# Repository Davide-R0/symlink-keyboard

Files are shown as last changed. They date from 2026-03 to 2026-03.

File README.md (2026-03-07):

# Keyboard

## Tools

- Build123d: for the viewer look [external editors](https://build123d.readthedocs.io/en/latest/external.html#external), in general we use: `yet-another-cad-viewer` (c'è una estensione per nvim o vscode?)
- SKiDL: to convert form kicad use tool: `netlist_to_skidl` (TODO: setup kicad liberary for this)
- Openscad to build123 migration: [look here](https://build123d.readthedocs.io/en/latest/OpenSCAD.html)
- for the pcb routing still use kicad editor

## General proprieties

- Layout `4x6+5`
- Parte sinistra il master, destro slave
- Si pososno caricare due firmwere diversi:
  - Bluetooth tra le due parti, se collegato il cavo intermedio e collegato il master al pc si caricano entrambe le schede. In entrambi i casi si può o collegare col cavo al pc per avere cablato il master o col bluetooth col master.
  - Cablato tra le due parti, in questo caso bisogna collegare il cavo tra le due parti e poi si può decidere se collegarla al pc tramite bluetooth o cavo con il master.
- led rgb per key e anche sul retro (led sotto tasti e sul retro sono in due lineee dati separati perchè quando va con batteria funzionano solo quelli sul retro, quando colelgato via cavo funzionano entrambi)
- schermo oled e potenziometro per lato
- Case "Sandwich Mount"
- Framework: `ZMK`, si possono creare moduli in C, supporta BLE e il nice!nano v2.
- Round trackpad (Circle Touchpad), mini touchpad. Il `TM023023-2024` su `Mouser` (c'è sia con overlay che senza, si può usare un nastro personalizzato se si vuole: ) per il connettore: connettore FPC 12-pin, 0.5mm pitch, bottom contact (52746-1271 ?). Altrimenti già completo (ma grande): [splitkb](https://splitkb.com/products/halcyon-cirque-touchpad-module?_pos=1&_sid=2299becd1&_ss=r). NOTA: forse ci sta anche al verisone da 35mm di diametro)

## Components

- Un micorcontroller `nice!nano v2` per lato (Pro Micro NRF52840) (Amazon o Aliexpress)
- Una batteria per lato sotto il microcontroller: `303040`, per la batteria forse fare un dopio fondo (cioè tagliare la back pcb e metterne un'altra che sporge di più sul retro così da poter mettere batterie più spesse (503040 o 503050)) (Aliexpress)
NOTE: le batterie anderebbero sempre circa 400-500mA (`403040`) a destra e 700-800mA (`403050`) a sinistra per consumo giusto.
- Un pannello oled per lato `0.91 inch OLED LCD Display IIC 128×32` (Amazon o Aliexpress)
- Un potenziometro a sinistra: `EC11` con click (LCSC)
- Un Circle Touchpad a destra: [splitkb](https://splitkb.com/products/halcyon-cirque-touchpad-module?_pos=1&_sid=2299becd1&_ss=r). Per la connesisone c'è bisogno di:
  - FPC a 12 pin: `FPC-05F-6PH20` (LCSC) (NOTE: è difficile da saldare? se dovesse essere cercare i "FPC to DIP breakout 12 pin 0.5mm")
  - Per il trackpad c'è un problema: macano i pin, bisogna usare un io expander: `PCA9536D` (4 pin extra) (LCSC)
- I switch `Kailh Choc V2 'Deep Sea' Brown` (tattili, low profile, silenziosi, con alloggio a croce) (Aliexpress)
- Socket per i switch `Kailh Choc Low Profile Socket` compatibili con choc. (Aliexpress) TODO: rivedere socket compatibili!
- Led rgb `SK6812MINI-E` per switch (trought hole) (LCSC)
- Led RGB `SK6812-5050` per la retorilluminazione (x6 per lato) (LCSC)a
- Per i led rgb di va un circuito che scollega l'alimentazione se non servonoe:
  - -- Transistor P-CH mosfet: `AO3401A` SOT-23 (LCSC)
  - -- Transistor N-CH mosfet: `AO3400A` SOT-23 (LCSC)
  - -- Resistena 100kohm: `ERJ6ENF1003V` 0805, per il pull-down per il P-CH (LCSC)
  - -- Resistena 10kohm: `TE05H1002BT` 0805, per il pull-up per il N-CH (LCSC)
  - Al posto dei mosfet grandi e resistenze meglio come: `TPS22917` + condensatore da 1nF: `CL21C102JBCNNNC` (LCSC)
- Resistenze 4.7kohm: `ERJU6RD4701V` 0805, per pullup per SDA e SCL (LCSC)
- Resistenza 400ohm: `TR0805B400RP0525Z` 0805, per l'ingresso DIN dei led (potrebbero esserci sovralimentazioni) (LCSC)
- Diodi: `1N4148W-E3-08` in SOD-123 per i led (cambiare il formato per facilità di saldatura?) (LCSC)
- Connection between split:
  - usb-c ports x2: `TYPE-C 16PIN 2MD`, per connessione tra due parti (LCSC)
  - ESD protection (Chip TVS): `USBLC6-2SC6`
  - PTC fuse (6V 1.5-2A): `1206L150/6V` (NOTE: forse meglio da 2A `1206L200/6V`) (LCSC)
  - Filtro RC per lo shield del usb-c: resistenza: (1kOhm) `RC0805FR-071KL`, condensatore (100nF 100V X7R) `CC0805X7R100V104MN`
  - Resistenza (5.1kohm): `0805W8F5101T5E`, per le connessioni pull-down CC1 CC2 (per alimentaizone)
  - Resistenza (22kohm) con supporto da 1.5A: `ERJ6ENF2202V`, per le connessioni pull-up CC1 CC2 (per alimentaizone)
  - Ideal Diode IC: `MAX40200AUK+T`, per il ritorno di corrente dalla porta (LCSC)
  - --Load switch IO (per protezione da correnti inverse): `TPS22918`
  - -- Diodi Zener da 3.3V: `BZT52C3V3-E3-18`, per protezione da collegamento scorretto (SOD-123) (LCSC)
  - -- resistenze: `0805W8F1000T5E`, 100 ohm 0805 per protezione da collegamento scorretto (LCSC)
- headers low profile: `Mill-Max Mfg. Corp. 315-43-112-41-003000`, to connect the nice!nano to the main pcb (and also the oled display) (LCSC) (OLD: header female connectors: `PM2.54-1X8PM-H85` (o altre versioni...))
- brass spacers M2 (+ viti): `Kit distanziatore in ottone` (Aliexpress)
- slider switch SMD : `PCM12SMTR`, per accendere/spegnere la batteria per ogni lato (LCSC)
- button SMD: verticale: `TL3342F450QG` oppure laterale: `SKSCLDE010`, per mettere la scheda in modalità bootloader. (LCSC)
- PCBs: "Sandwich Mount":
  - Layout:
    - Top Plate: dove voengono incastrati i switch
    - Main PCB: dove c'è tuta la elettornica
    - Bottom Plate: per proteggere la eletronica deall'esterno.
  - Il tutto connesso isnieme con viti M.2 e distanziali in ottone:
    - Tra il main pcb e il Top plate non is mettono distanziali perchè sono gli switch a tenere il palte.
    - Tra main pcb e botton plate: distanziali tra `6-8mm`.
  - Per la pendenza o si mettono distanziali assimmetrici,oppure si usa il `Tenting Puck`, (JLCPCB)
- Livellatore di tensione (Level Shifter): `SN74LVC1T45DBVR` per la linea dati dei led (LCSC)
- Per prioteggere sovratensioni TX/RX un Logic Buffer: `SN74LVC2G34DBVR` (LCSC)
- --Diodo Schottky: `SS14`, per il ritorno della batteria quando sono collegati tramite filo le due parti (LCSC)
- Kampton tape: per l'isolamento e resistenza al calore (Aliexpress)
- Pasta saldante: per componenti smd (Aliexpress)

Switch Kailh Choc V2: Ottimi, ma ricorda che hanno un'altezza diversa dai V1. Il tuo "Top Plate" deve avere uno spessore di $1.2\text{ mm}$ o $1.5\text{ mm}$ (taglio laser o PCB) per permettere agli switch di "cliccare" correttamente in posizione.

NOTE: per i componenti smd i formati da scegliere sono:

- SOT-23 per i chip a più gambe
- 0805 per R, C e componenti a 2 gambe

QT_QPA_PLATFORM=xcb freecad

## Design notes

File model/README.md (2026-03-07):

per i distanziatori esagonali e per lassemblaggio delel parti (dove si possono definire gli "anchors") usare la libreria: `BOSL2`

Ad esempio: 
include <BOSL2/std.scad>

// Il cubo non è al centro, ma "poggia" sul piano con la faccia inferiore
cuboid([20, 20, 20], anchor=BOTTOM);

cuboid([10, 10, 5], anchor=BOTTOM) {
    attach(TOP) 
        cyl(d=3, l=10, anchor=BOTTOM);
}

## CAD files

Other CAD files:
model/legacy/config.scad
model/legacy/main.scad
model/legacy/main-plate/main-plate.scad

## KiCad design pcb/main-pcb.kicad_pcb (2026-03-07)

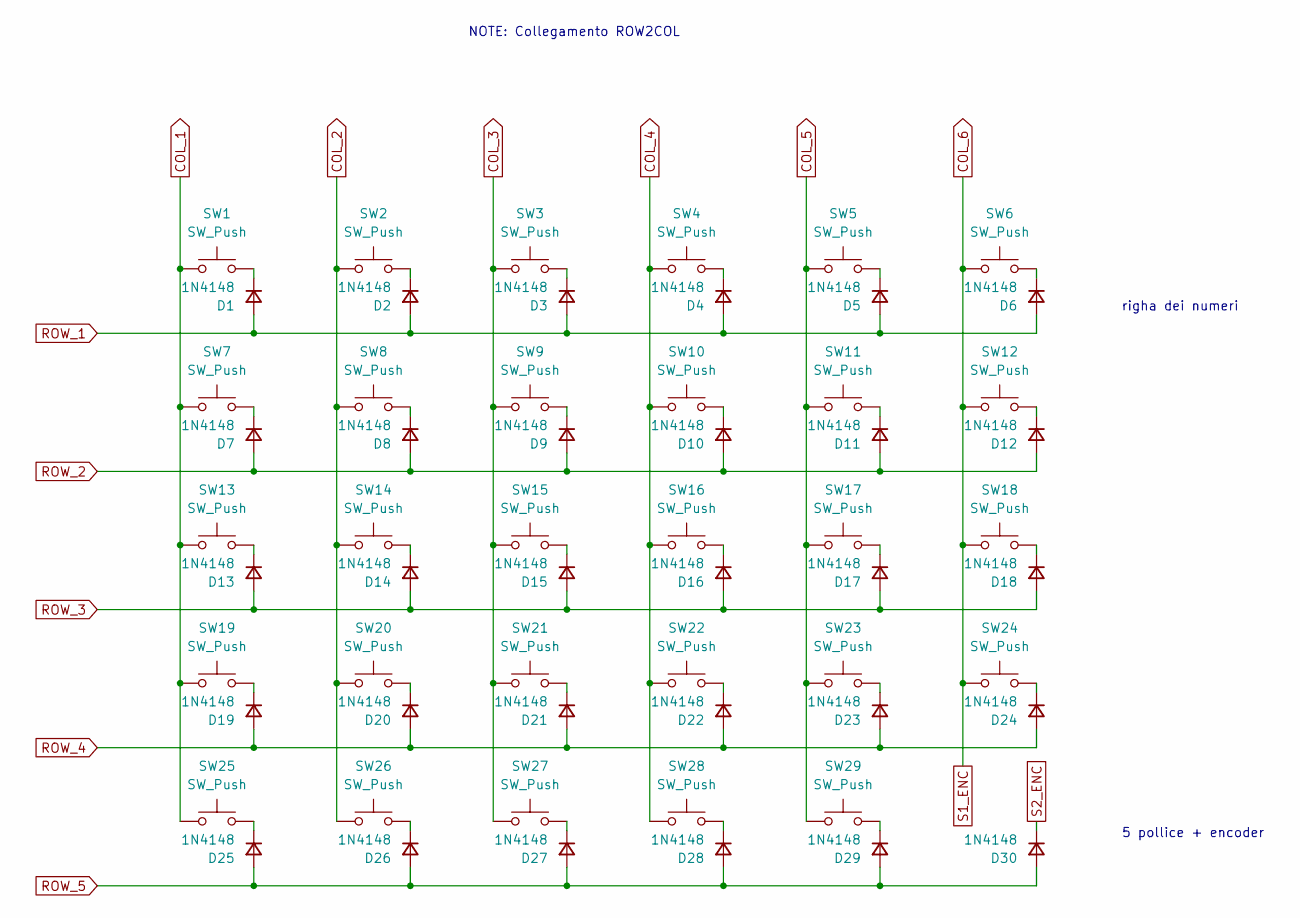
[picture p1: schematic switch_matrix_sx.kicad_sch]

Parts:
D1, D2, D3, D4, D5, D6, D7, D8, D9, D10, D11, D12, D13, D14, D15, D16, D17, D18, D19, D20, D21, D22, D23, D24, D25, D26, D27, D28, D29, D30: 1N4148; D_SOD-123
SW1, SW2, SW3, SW4, SW5, SW6, SW7, SW8, SW9, SW10, SW11, SW12, SW13, SW14, SW15, SW16, SW17, SW18, SW19, SW20, SW21, SW22, SW23, SW24, SW25, SW26, SW27, SW28, SW29: SW_Push; SW_Hotswap_Kailh_Choc_V2_1.00u

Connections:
COL_1: SW1.1, SW7.1, SW13.1, SW19.1, SW25.1; also elsewhere on the board
COL_2: SW2.1, SW8.1, SW14.1, SW20.1, SW26.1; also elsewhere on the board
COL_3: SW3.1, SW9.1, SW15.1, SW21.1, SW27.1; also elsewhere on the board
COL_4: SW4.1, SW10.1, SW16.1, SW22.1, SW28.1; also elsewhere on the board
COL_5: SW5.1, SW11.1, SW17.1, SW23.1, SW29.1; also elsewhere on the board
COL_6: SW6.1, SW12.1, SW18.1, SW24.1; also elsewhere on the board
unnamed: D1.1 (K), SW1.2
unnamed: D2.1 (K), SW2.2
unnamed: D3.1 (K), SW3.2
unnamed: D4.1 (K), SW4.2
unnamed: D5.1 (K), SW5.2
unnamed: D6.1 (K), SW6.2
unnamed: D7.1 (K), SW7.2
unnamed: D8.1 (K), SW8.2
unnamed: D9.1 (K), SW9.2
unnamed: D10.1 (K), SW10.2
unnamed: D11.1 (K), SW11.2
unnamed: D12.1 (K), SW12.2
unnamed: D13.1 (K), SW13.2
unnamed: D14.1 (K), SW14.2
unnamed: D15.1 (K), SW15.2
unnamed: D16.1 (K), SW16.2
unnamed: D17.1 (K), SW17.2
unnamed: D18.1 (K), SW18.2
unnamed: D19.1 (K), SW19.2
unnamed: D20.1 (K), SW20.2
unnamed: D21.1 (K), SW21.2
unnamed: D22.1 (K), SW22.2
unnamed: D23.1 (K), SW23.2
unnamed: D24.1 (K), SW24.2
unnamed: D25.1 (K), SW25.2
unnamed: D26.1 (K), SW26.2
unnamed: D27.1 (K), SW27.2
unnamed: D28.1 (K), SW28.2
unnamed: D29.1 (K), SW29.2
ROW_1: D1.2 (A), D2.2 (A), D3.2 (A), D4.2 (A), D5.2 (A), D6.2 (A); also elsewhere on the board
ROW_2: D7.2 (A), D8.2 (A), D9.2 (A), D10.2 (A), D11.2 (A), D12.2 (A); also elsewhere on the board
ROW_3: D13.2 (A), D14.2 (A), D15.2 (A), D16.2 (A), D17.2 (A), D18.2 (A); also elsewhere on the board
ROW_4: D19.2 (A), D20.2 (A), D21.2 (A), D22.2 (A), D23.2 (A), D24.2 (A); also elsewhere on the board
ROW_5: D25.2 (A), D26.2 (A), D27.2 (A), D28.2 (A), D29.2 (A), D30.2 (A); also elsewhere on the board
S2_ENC: D30.1 (K); also elsewhere on the board

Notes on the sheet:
NOTE: Collegamento ROW2COL
5 pollice + encoder
righa dei numeri

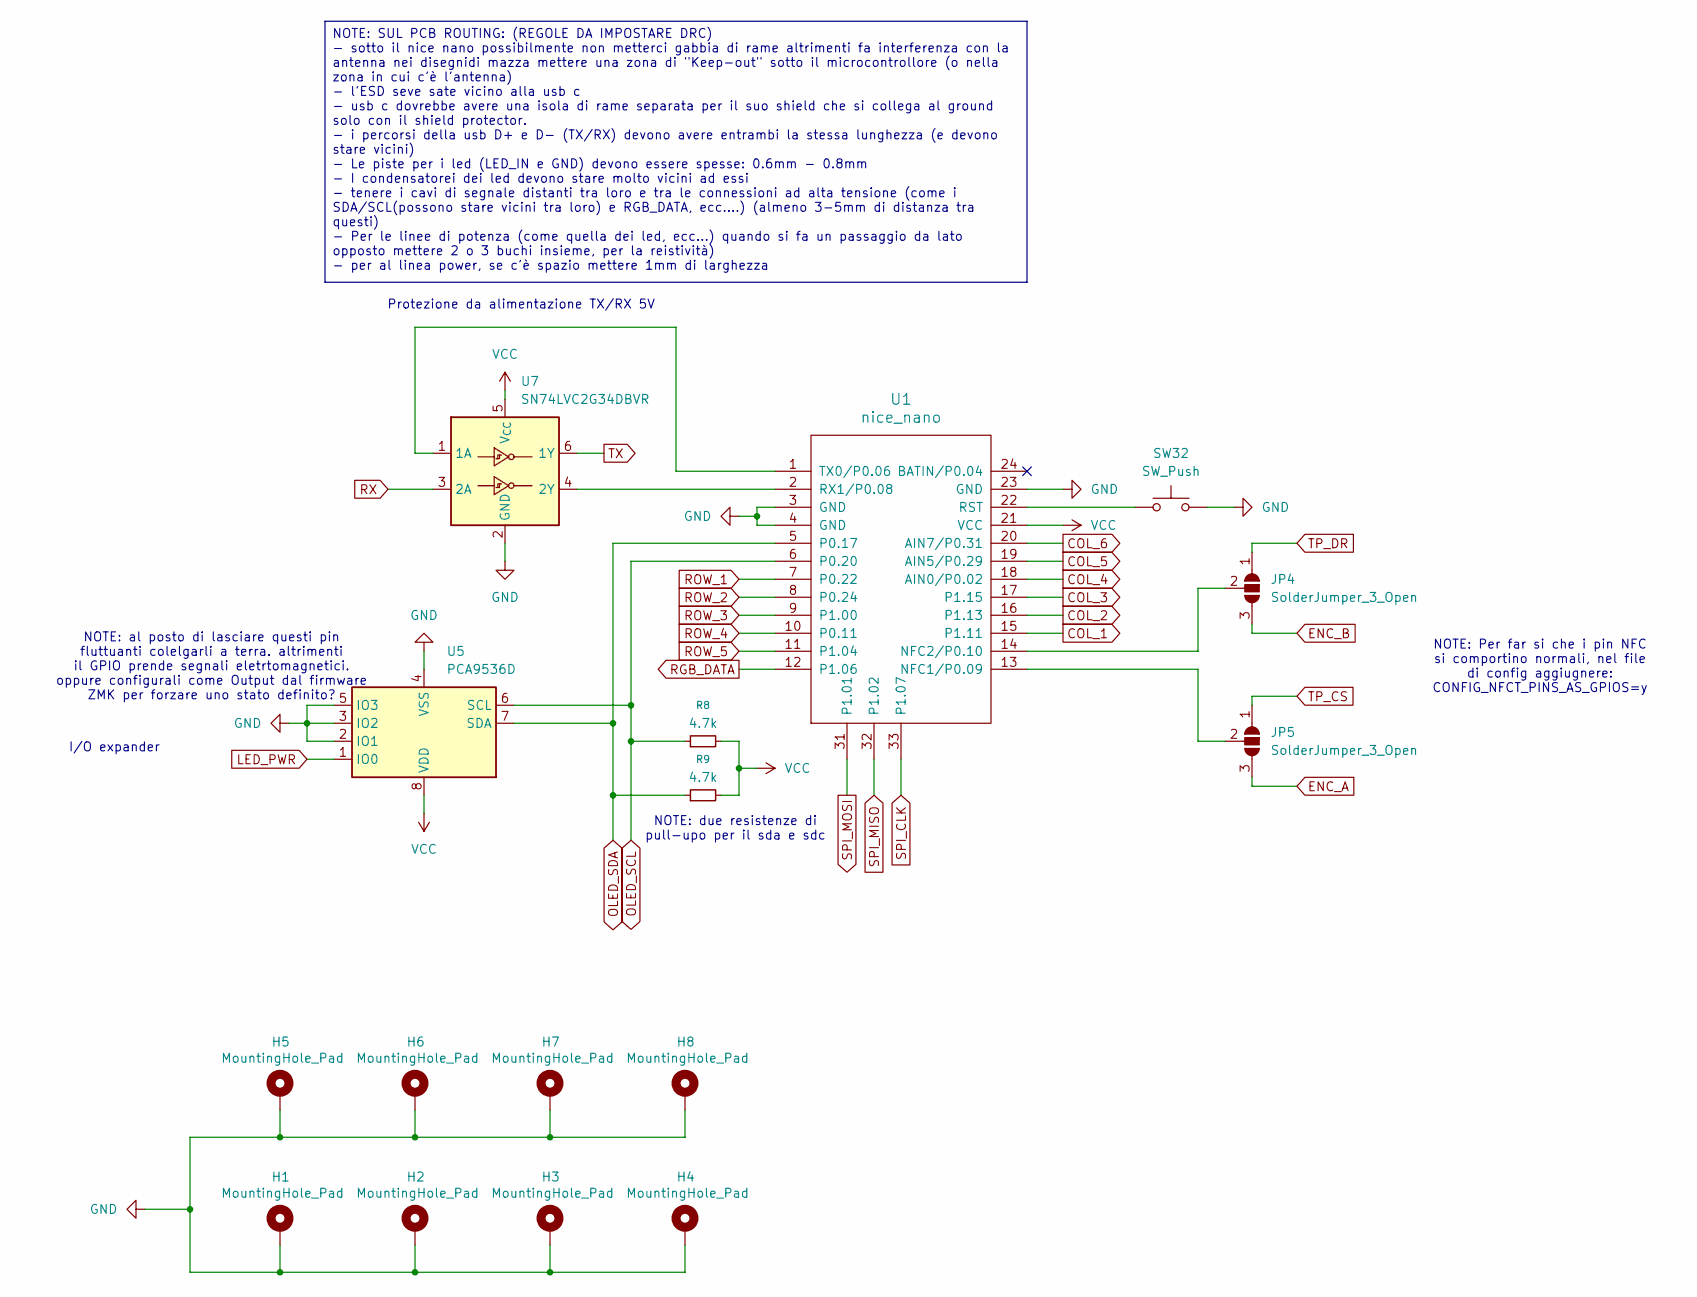
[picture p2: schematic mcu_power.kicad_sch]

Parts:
H1, H2, H3, H4, H5, H6, H7, H8: MountingHole_Pad
JP4, JP5: SolderJumper_3_Open; SolderJumper-3_P1.3mm_Open_RoundedPad1.0x1.5mm_NumberLabels
R8, R9: 4.7k; R_0805_2012Metric_Pad1.20x1.40mm_HandSolder
SW32: SW_Push; SW_SPST_TL3342
U1: nice_nano
U5: PCA9536D; SOIC-8_3.9x4.9mm_P1.27mm
U7: SN74LVC2G34DBVR; SOT-23-6

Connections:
COL_1: U1.15 (P1.11); also elsewhere on the board
COL_2: U1.16 (P1.13); also elsewhere on the board
COL_3: U1.17 (P1.15); also elsewhere on the board
COL_4: U1.18 (AIN0/P0.02); also elsewhere on the board
COL_5: U1.19 (AIN5/P0.29); also elsewhere on the board
COL_6: U1.20 (AIN7/P0.31); also elsewhere on the board
ENC_A: JP5.3 (B); also elsewhere on the board
ENC_B: JP4.3 (B); also elsewhere on the board
GND: H1.1, H2.1, H3.1, H4.1, H5.1, H6.1, H7.1, H8.1, SW32.2, U1.3 (GND), U1.4 (GND), U1.23 (GND), U5.2 (IO1), U5.3 (IO2), U5.4 (VSS), U5.5 (IO3), U7.2 (GND); also elsewhere on the board
LED_PWR: U5.1 (IO0); also elsewhere on the board
unnamed: JP4.2 (C), U1.14 (NFC2/P0.10)
unnamed: JP5.2 (C), U1.13 (NFC1/P0.09)
unnamed: SW32.1, U1.22 (RST)
unnamed: U1.2 (RX1/P0.08), U7.4 (2Y)
unnamed: U1.1 (TX0/P0.06), U7.1 (1A)
OLED_SCL: R8.1, U1.6 (P0.20), U5.6 (SCL); also elsewhere on the board
OLED_SDA: R9.1, U1.5 (P0.17), U5.7 (SDA); also elsewhere on the board
RGB_DATA: U1.12 (P1.06); also elsewhere on the board
ROW_1: U1.7 (P0.22); also elsewhere on the board
ROW_2: U1.8 (P0.24); also elsewhere on the board
ROW_3: U1.9 (P1.00); also elsewhere on the board
ROW_4: U1.10 (P0.11); also elsewhere on the board
ROW_5: U1.11 (P1.04); also elsewhere on the board
RX: U7.3 (2A); also elsewhere on the board
SPI_CLK: U1.33 (P1.07); also elsewhere on the board
SPI_MISO: U1.32 (P1.02); also elsewhere on the board
SPI_MOSI: U1.31 (P1.01); also elsewhere on the board
TP_CS: JP5.1 (A); also elsewhere on the board
TP_DR: JP4.1 (A); also elsewhere on the board
TX: U7.6 (1Y); also elsewhere on the board
VCC: R8.2, R9.2, U1.21 (VCC), U5.8 (VDD), U7.5 (V_{CC}); also elsewhere on the board

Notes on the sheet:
NOTE: Per far si che i pin NFC si comportino normali, nel file di config aggiugnere: CONFIG_NFCT_PINS_AS_GPIOS=y
NOTE: al posto di lasciare questi pin fluttuanti colelgarli a terra. altrimenti il GPIO prende segnali eletrtomagnetici. oppure configurali come Output dal firmware ZMK per forzare uno stato definito?
I/O expander
Protezione da alimentazione TX/RX 5V
NOTE: due resistenze di pull-upo per il sda e sdc
NOTE: SUL PCB ROUTING: (REGOLE DA IMPOSTARE DRC) - sotto il nice nano possibilmente non metterci gabbia di rame altrimenti fa interferenza con la antenna nei disegnidi mazza mettere una zona di "Keep-out" sotto il microcontrollore (o nella zona in cui c'è l'antenna) - l'ESD seve sate vicino alla us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

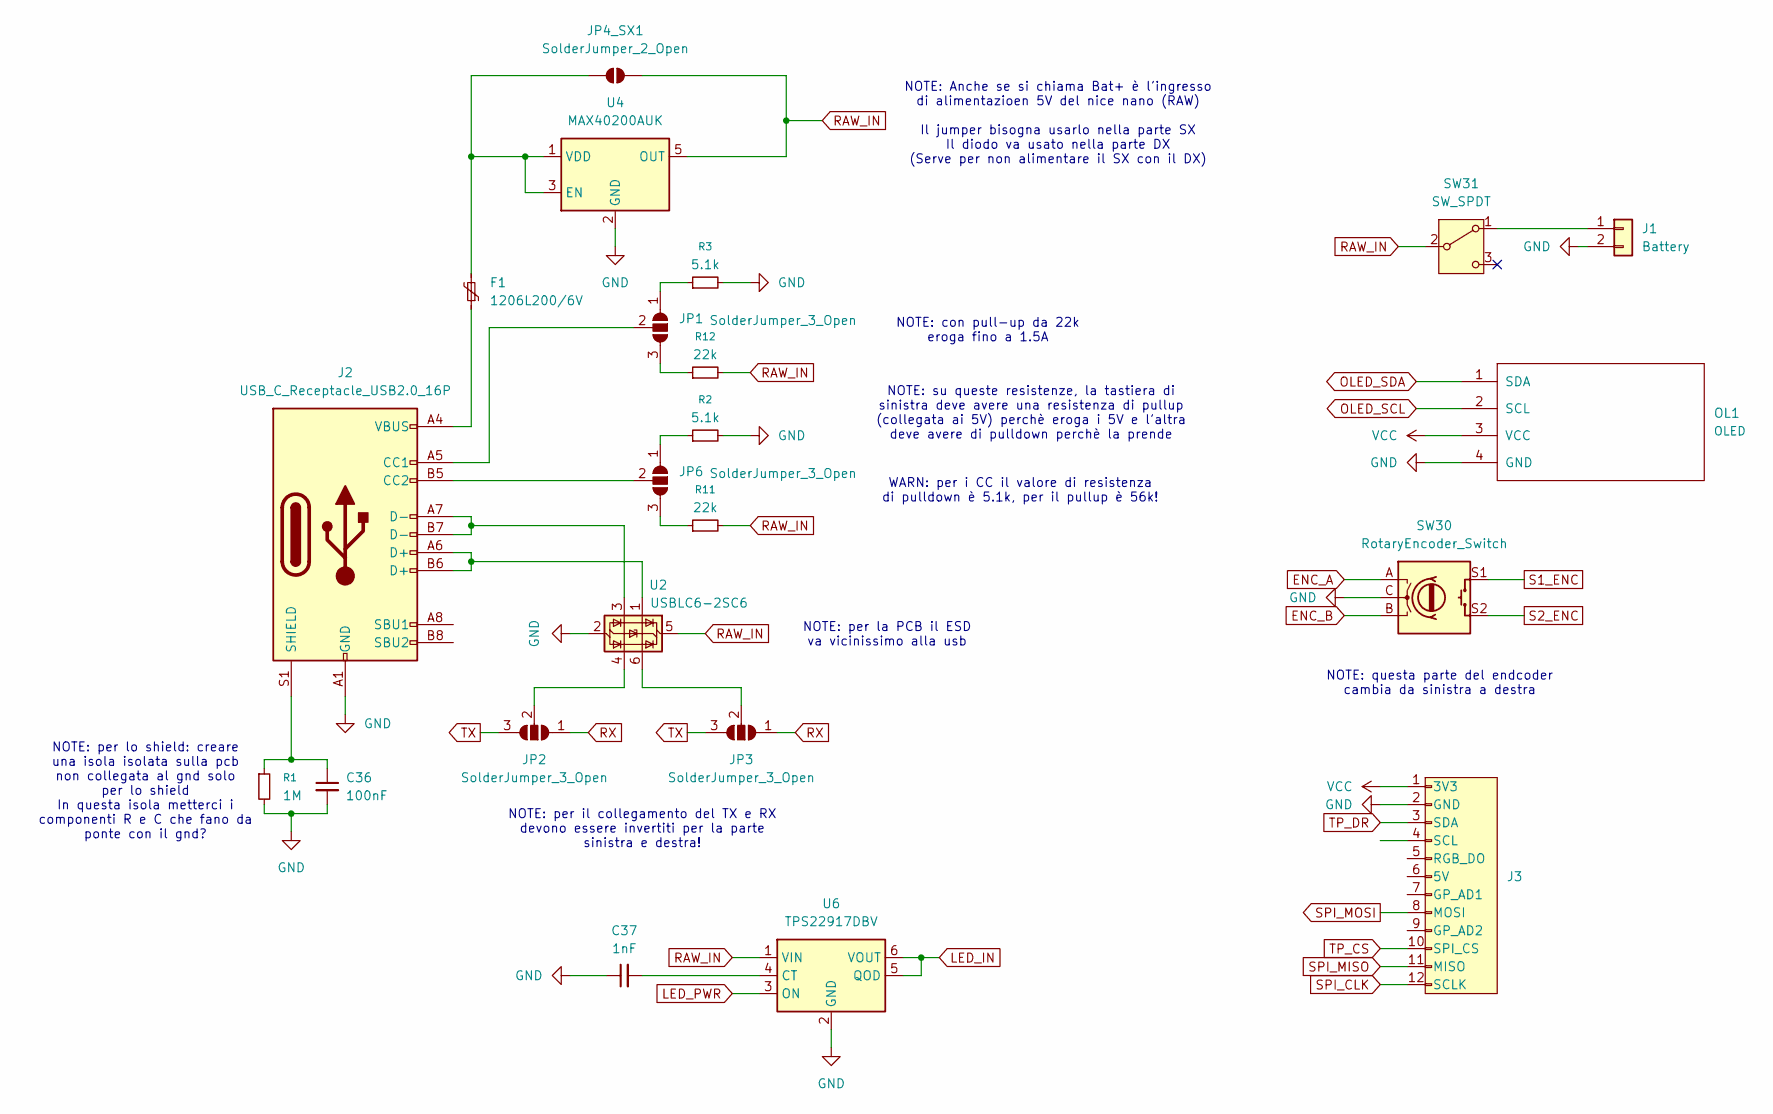
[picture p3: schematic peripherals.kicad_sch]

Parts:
C36: 100nF; C_0805_2012Metric_Pad1.18x1.45mm_HandSolder
C37: 1nF; C_0805_2012Metric_Pad1.18x1.45mm_HandSolder
F1: 1206L200/6V; Fuse_1206_3216Metric
J1: Battery; JST_PH_S2B-PH-K_1x02_P2.00mm_Horizontal
J2: USB_C_Receptacle_USB2.0_16P; USB_C_Receptacle_HRO_TYPE-C-31-M-12
J3: JUSHUO_AFA07-S12FCA-00_1x12-1MP_P1.0mm_Horizontal
JP1, JP2, JP3, JP6: SolderJumper_3_Open; SolderJumper-3_P1.3mm_Open_RoundedPad1.0x1.5mm_NumberLabels
JP4_SX1: SolderJumper_2_Open; SolderJumper-2_P1.3mm_Open_RoundedPad1.0x1.5mm
OL1: OLED; OLED_v2
R1: 1M; R_0805_2012Metric_Pad1.20x1.40mm_HandSolder
R2, R3: 5.1k; R_0805_2012Metric_Pad1.20x1.40mm_HandSolder
R11, R12: 22k; R_0805_2012Metric_Pad1.20x1.40mm_HandSolder
SW30: RotaryEncoder_Switch; RotaryEncoder_Alps_EC11E-Switch_Vertical_H20mm
SW31: SW_SPDT; SW_SPDT_PCM12
U2: USBLC6-2SC6; SOT-23-6
U4: MAX40200AUK; SOT-23-5
U6: TPS22917DBV; SOT-23-6

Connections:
COL_6: SW30.S1; also elsewhere on the board
ENC_A: SW30.A; also elsewhere on the board
ENC_B: SW30.B; also elsewhere on the board
GND: C36.2, C37.1, J1.2, J2.A1 (GND), J2.A12 (GND), J2.B1 (GND), J2.B12 (GND), J3.2 (GND), OL1.4 (GND), R1.2, R2.2, R3.2, SW30.C, U2.2 (GND), U4.2 (GND), U6.2 (GND); also elsewhere on the board
LED_IN: U6.5 (QOD), U6.6 (VOUT); also elsewhere on the board
LED_PWR: U6.3 (ON); also elsewhere on the board
unnamed: F1.1, J2.A4 (VBUS), J2.A9 (VBUS), J2.B4 (VBUS), J2.B9 (VBUS)
unnamed: J1.1, SW31.1 (A)
unnamed: J2.A5 (CC1), JP1.2 (C)
unnamed: J2.B5 (CC2), JP6.2 (C)
unnamed: J2.A6 (D+), J2.B6 (D+), U2.1 (I/O1)
unnamed: J2.A7 (D-), J2.B7 (D-), U2.3 (I/O2)
unnamed: C36.1, J2.S1 (SHIELD), R1.1
unnamed: JP1.1 (A), R3.1
unnamed: JP1.3 (B), R12.1
unnamed: JP2.2 (C), U2.4 (I/O2)
unnamed: JP3.2 (C), U2.6 (I/O1)
unnamed: F1.2, JP4_SX1.2 (B), U4.1 (VDD), U4.3 (EN)
unnamed: JP6.1 (A), R2.1
unnamed: JP6.3 (B), R11.1
unnamed: C37.2, U6.4 (CT)
OLED_SCL: OL1.2 (SCL); also elsewhere on the board
OLED_SDA: OL1.1 (SDA); also elsewhere on the board
RAW_IN: JP4_SX1.1 (A), R11.2, R12.2, SW31.2 (B), U2.5 (VBUS), U4.5 (OUT), U6.1 (VIN); also elsewhere on the board
RX: JP2.1 (A), JP3.1 (A); also elsewhere on the board
S2_ENC: SW30.S2; also elsewhere on the board
SPI_CLK: J3.12 (SCLK); also elsewhere on the board
SPI_MISO: J3.11 (MISO); also elsewhere on the board
SPI_MOSI: J3.8 (MOSI); also elsewhere on the board
TP_CS: J3.10 (SPI_CS); also elsewhere on the board
TP_DR: J3.3 (SDA); also elsewhere on the board
TX: JP2.3 (B), JP3.3 (B); also elsewhere on the board
VCC: J3.1 (3V3), OL1.3 (VCC); also elsewhere on the board

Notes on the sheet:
NOTE: per lo shield: creare una isola isolata sulla pcb non collegata al gnd solo per lo shield In questa isola metterci i componenti R e C che fano da ponte con il gnd?
NOTE: questa parte del endcoder cambia da sinistra a destra
WARN: per i CC il valore di resistenza di pulldown è 5.1k, per il pullup è 56k!
NOTE: per il collegamento del TX e RX devono essere invertiti per la parte sinistra e destra!
NOTE: per la PCB il ESD va vicinissimo alla usb
NOTE: su queste resistenze, la tastiera di sinistra deve avere una resistenza di pullup (collegata ai 5V) perchè eroga i 5V e l'altra deve avere di pulldown perchè la prende
NOTE: Anche se si chiama Bat+ è l'ingresso di alimentazioen 5V del nice nano (RAW) Il jumper bisogna usarlo nella parte SX Il diodo va usato nella parte DX (Serve per non alimentare il SX con il DX)
NOTE: con pull-up da 22k eroga fino a 1.5A

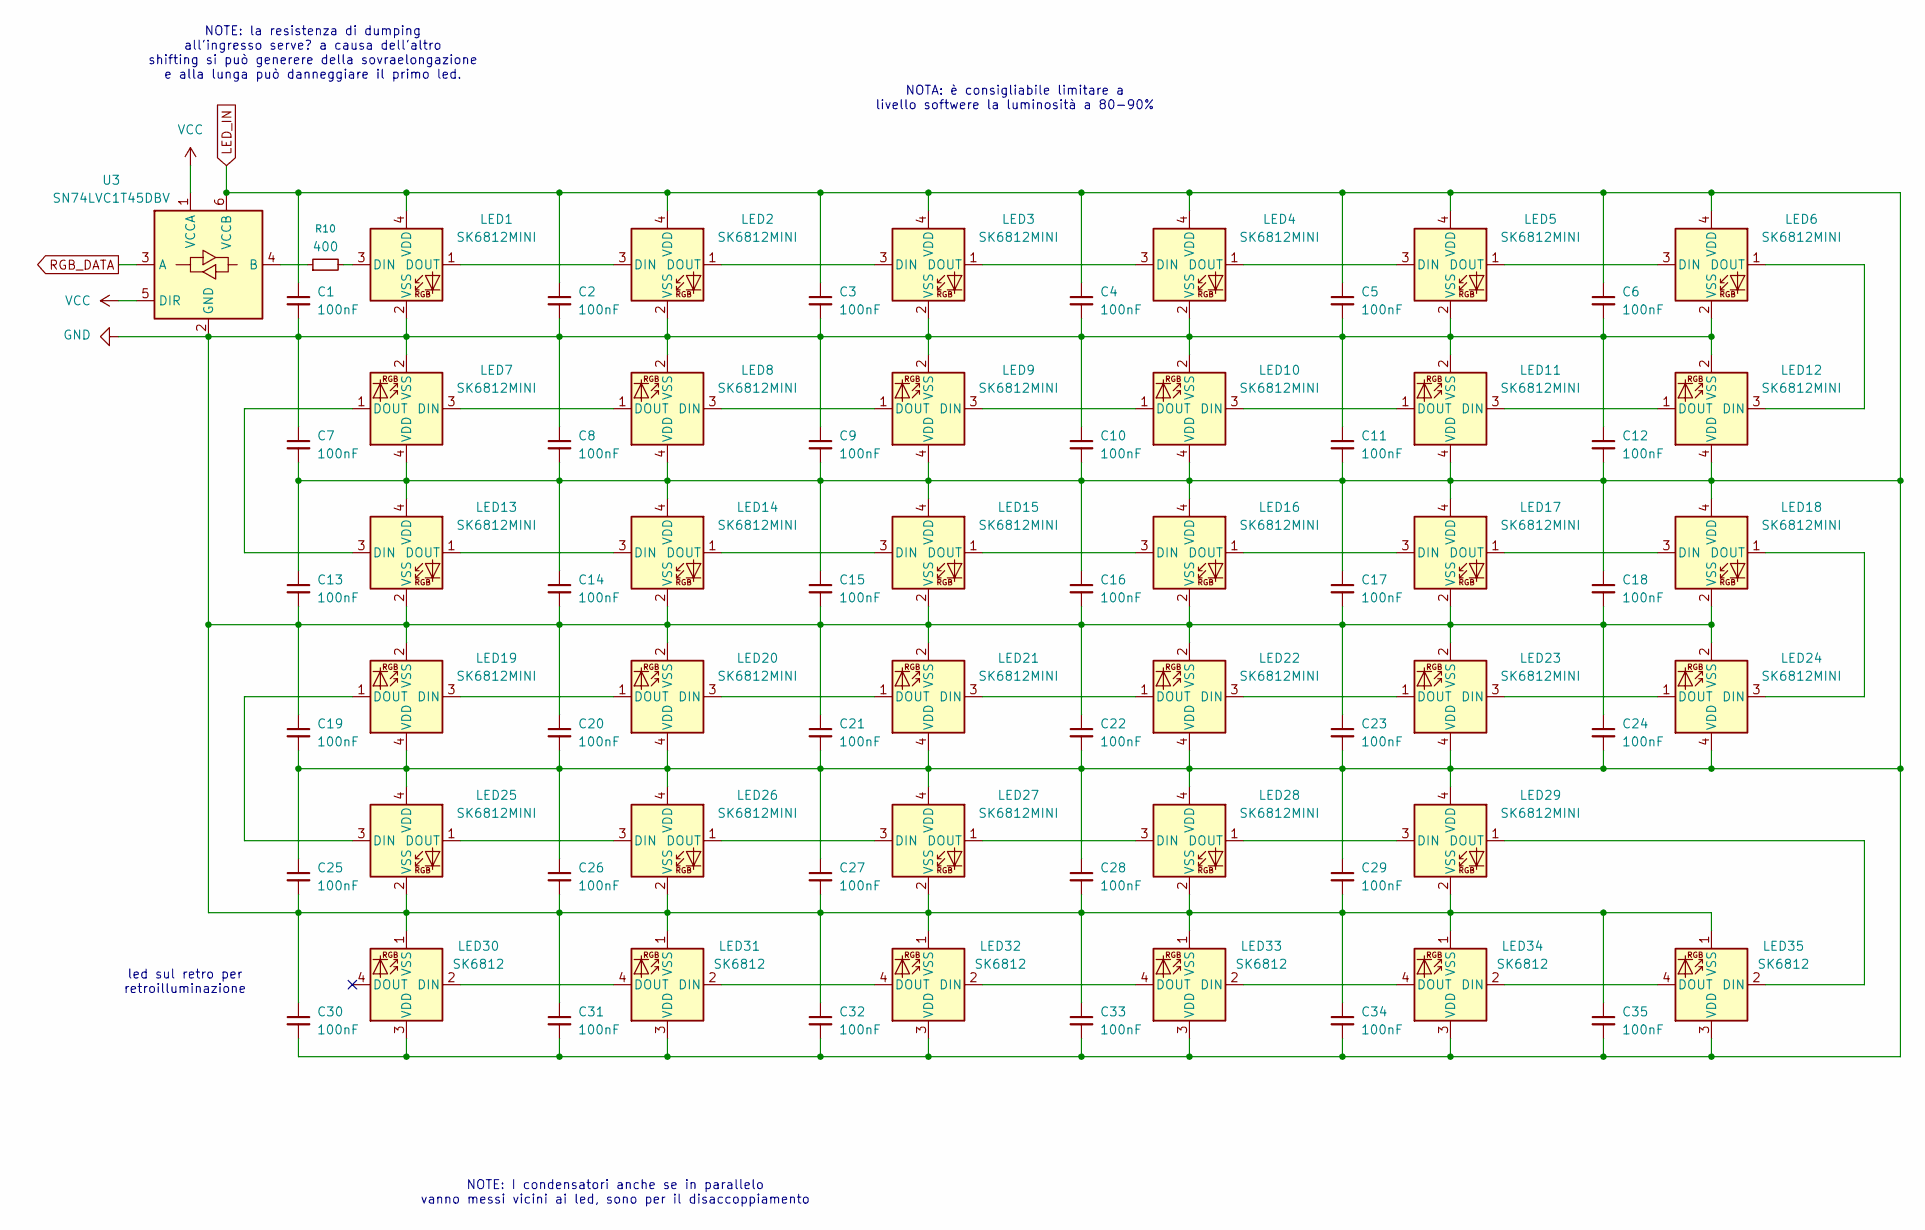
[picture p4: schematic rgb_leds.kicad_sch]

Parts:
C1, C2, C3, C4, C5, C6, C7, C8, C9, C10, C11, C12, C13, C14, C15, C16, C17, C18, C19, C20, C21, C22, C23, C24, C25, C26, C27, C28, C29, C30, C31, C32, C33, C34, C35: 100nF; C_0805_2012Metric
LED1, LED2, LED3, LED4, LED5, LED6, LED7, LED8, LED9, LED10, LED11, LED12, LED13, LED14, LED15, LED16, LED17, LED18, LED19, LED20, LED21, LED22, LED23, LED24, LED25, LED26, LED27, LED28, LED29: SK6812MINI; SK6812-MINI-E
LED30, LED31, LED32, LED33, LED34, LED35: SK6812; LED_OPSCO_SK6812_PLCC4_5.0x5.0mm_P3.1mm
R10: 400; R_0805_2012Metric_Pad1.20x1.40mm_HandSolder
U3: SN74LVC1T45DBV; SOT-23-6

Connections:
GND: C1.2, C2.2, C3.2, C4.2, C5.2, C6.2, C7.1, C8.1, C9.1, C10.1, C11.1, C12.1, C13.2, C14.2, C15.2, C16.2, C17.2, C18.2, C19.1, C20.1, C21.1, C22.1, C23.1, C24.1, C25.2, C26.2, C27.2, C28.2, C29.2, C30.1, C31.1, C32.1, C33.1, C34.1, C35.1, LED1.2 (VSS), LED2.2 (VSS), LED3.2 (VSS), LED4.2 (VSS), LED5.2 (VSS), LED6.2 (VSS), LED7.2 (VSS), LED8.2 (VSS), LED9.2 (VSS), LED10.2 (VSS), LED11.2 (VSS), LED12.2 (VSS), LED13.2 (VSS), LED14.2 (VSS), LED15.2 (VSS), LED16.2 (VSS), LED17.2 (VSS), LED18.2 (VSS), LED19.2 (VSS), LED20.2 (VSS), LED21.2 (VSS), LED22.2 (VSS), LED23.2 (VSS), LED24.2 (VSS), LED25.2 (VSS), LED26.2 (VSS), LED27.2 (VSS), LED28.2 (VSS), LED29.2 (VSS), LED30.1 (VSS), LED31.1 (VSS), LED32.1 (VSS), LED33.1 (VSS), LED34.1 (VSS), LED35.1 (VSS), U3.2 (GND); also elsewhere on the board
LED_IN: C1.1, C2.1, C3.1, C4.1, C5.1, C6.1, C7.2, C8.2, C9.2, C10.2, C11.2, C12.2, C13.1, C14.1, C15.1, C16.1, C17.1, C18.1, C19.2, C20.2, C21.2, C22.2, C23.2, C24.2, C25.1, C26.1, C27.1, C28.1, C29.1, C30.2, C31.2, C32.2, C33.2, C34.2, C35.2, LED1.4 (VDD), LED2.4 (VDD), LED3.4 (VDD), LED4.4 (VDD), LED5.4 (VDD), LED6.4 (VDD), LED7.4 (VDD), LED8.4 (VDD), LED9.4 (VDD), LED10.4 (VDD), LED11.4 (VDD), LED12.4 (VDD), LED13.4 (VDD), LED14.4 (VDD), LED15.4 (VDD), LED16.4 (VDD), LED17.4 (VDD), LED18.4 (VDD), LED19.4 (VDD), LED20.4 (VDD), LED21.4 (VDD), LED22.4 (VDD), LED23.4 (VDD), LED24.4 (VDD), LED25.4 (VDD), LED26.4 (VDD), LED27.4 (VDD), LED28.4 (VDD), LED29.4 (VDD), LED30.3 (VDD), LED31.3 (VDD), LED32.3 (VDD), LED33.3 (VDD), LED34.3 (VDD), LED35.3 (VDD), U3.6 (VCCB); also elsewhere on the board
unnamed: LED1.3 (DIN), R10.2
unnamed: LED1.1 (DOUT), LED2.3 (DIN)
unnamed: LED2.1 (DOUT), LED3.3 (DIN)
unnamed: LED3.1 (DOUT), LED4.3 (DIN)
unnamed: LED4.1 (DOUT), LED5.3 (DIN)
unnamed: LED5.1 (DOUT), LED6.3 (DIN)
unnamed: LED7.3 (DIN), LED8.1 (DOUT)
unnamed: LED8.3 (DIN), LED9.1 (DOUT)
unnamed: LED10.3 (DIN), LED11.1 (DOUT)
unnamed: LED9.3 (DIN), LED10.1 (DOUT)
unnamed: LED11.3 (DIN), LED12.1 (DOUT)
unnamed: LED6.1 (DOUT), LED12.3 (DIN)
unnamed: LED7.1 (DOUT), LED13.3 (DIN)
unnamed: LED13.1 (DOUT), LED14.3 (DIN)
unnamed: LED14.1 (DOUT), LED15.3 (DIN)
unnamed: LED15.1 (DOUT), LED16.3 (DIN)
unnamed: LED16.1 (DOUT), LED17.3 (DIN)
unnamed: LED17.1 (DOUT), LED18.3 (DIN)
unnamed: LED18.1 (DOUT), LED24.3 (DIN)
unnamed: LED19.3 (DIN), LED20.1 (DOUT)
unnamed: LED19.1 (DOUT), LED25.3 (DIN)
unnamed: LED20.3 (DIN), LED21.1 (DOUT)
unnamed: LED21.3 (DIN), LED22.1 (DOUT)
unnamed: LED22.3 (DIN), LED23.1 (DOUT)
unnamed: LED23.3 (DIN), LED24.1 (DOUT)
unnamed: LED25.1 (DOUT), LED26.3 (DIN)
unnamed: LED26.1 (DOUT), LED27.3 (DIN)
unnamed: LED27.1 (DOUT), LED28.3 (DIN)
unnamed: LED28.1 (DOUT), LED29.3 (DIN)
unnamed: LED29.1 (DOUT), LED35.2 (DIN)
unnamed: LED30.2 (DIN), LED31.4 (DOUT)
unnamed: LED31.2 (DIN), LED32.4 (DOUT)
unnamed: LED32.2 (DIN), LED33.4 (DOUT)
unnamed: LED33.2 (DIN), LED34.4 (DOUT)
unnamed: LED34.2 (DIN), LED35.4 (DOUT)
unnamed: R10.1, U3.4 (B)
RGB_DATA: U3.3 (A); also elsewhere on the board
VCC: U3.1 (VCCA), U3.5 (DIR); also elsewhere on the board

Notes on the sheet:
led sul retro per retroilluminazione
NOTE: I condensatori anche se in parallelo vanno messi vicini ai led, sono per il disaccoppiamento
NOTA: è consigliabile limitare a livello softwere la luminosità a 80-90%
NOTE: la resistenza di dumping all'ingresso serve? a causa dell'altro shifting si può generere della sovraelongazione e alla lunga può danneggiare il primo led.

Board: 2 copper layers, 162 parts (101 on the bottom side), 114 nets, no tracks yet.

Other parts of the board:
D31_DX1: SS14; D_SMA

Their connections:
RAW_IN: D31_DX1.1 (K); also elsewhere on the board

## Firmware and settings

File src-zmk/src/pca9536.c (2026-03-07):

// 1. Dichiariamo a quale nodo del Device Tree risponde questo driver
#define DT_DRV_COMPAT custom_pca9536

#include <zephyr/kernel.h>
#include <zephyr/device.h>
#include <zephyr/drivers/i2c.h>
#include <zephyr/logging/log.h>

// Inizializza il logger di Zephyr per poter fare debug
LOG_MODULE_REGISTER(pca9536, LOG_LEVEL_INF);

// 2. Struttura di configurazione (i dati presi dall'overlay)
struct pca9536_config {
    struct i2c_dt_spec i2c; // Contiene il bus I2C e l'indirizzo (0x41)
};

// 3. Funzione di utilità per scrivere un registro I2C
static int pca9536_write_reg(const struct device *dev, uint8_t reg, uint8_t val) {
    const struct pca9536_config *config = dev->config;
    uint8_t buf[2] = {reg, val};
    
    // Usa le API I2C native di Zephyr
    return i2c_write_dt(&config->i2c, buf, sizeof(buf));
}

// 4. La funzione di inizializzazione che Zephyr chiama al boot
static int pca9536_init(const struct device *dev) {
    const struct pca9536_config *config = dev->config;

    // Controlla se il bus I2C è pronto (es. i pin sono configurati bene)
    if (!i2c_is_ready_dt(&config->i2c)) {
        LOG_ERR("Bus I2C non pronto per PCA9536");
        return -ENODEV;
    }

    LOG_INF("PCA9536 inizializzato con successo sull'indirizzo 0x%02x", config->i2c.addr);

    // Esempio: Scriviamo nel registro di configurazione (0x03) per settare i pin come output (0x00)
    // pca9536_write_reg(dev, 0x03, 0x00);

    return 0;
}

// 5. La macro magica di Zephyr
// Questa macro cerca tutti i nodi nell'overlay con compatible="custom,pca9536"
// e per ognuno crea l'istanza e chiama pca9536_init al momento giusto dell'avvio.
#define PCA9536_DEFINE(inst)                                            \
    static const struct pca9536_config pca9536_config_##inst = {        \
        .i2c = I2C_DT_SPEC_INST_GET(inst),                              \
    };                                                                  \
                                                                        \
    DEVICE_DT_INST_DEFINE(inst, pca9536_init, NULL,                     \
                          NULL, &pca9536_config_##inst,                 \
                          POST_KERNEL, CONFIG_SENSOR_INIT_PRIORITY,     \
                          NULL);

// Esegue la macro per ogni istanza trovata (tu ne avrai 1)
DT_INST_FOREACH_STATUS_OKAY(PCA9536_DEFINE)
